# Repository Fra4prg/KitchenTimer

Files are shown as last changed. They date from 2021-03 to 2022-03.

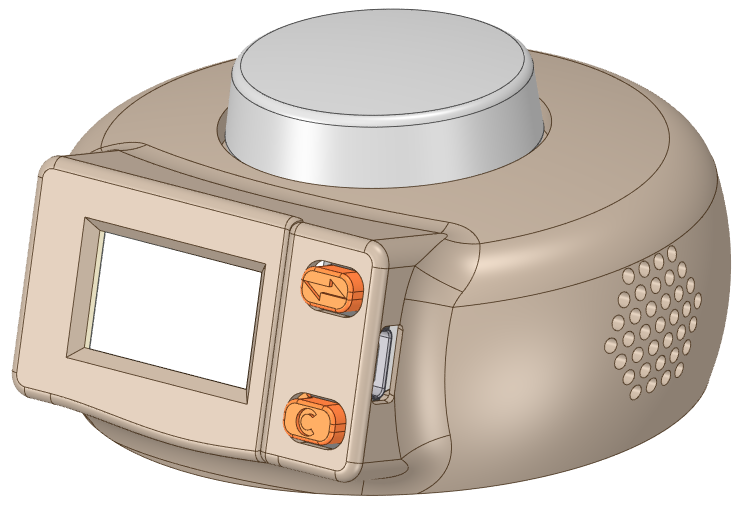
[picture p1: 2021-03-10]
pictures/Kitchen_Timer_1.png

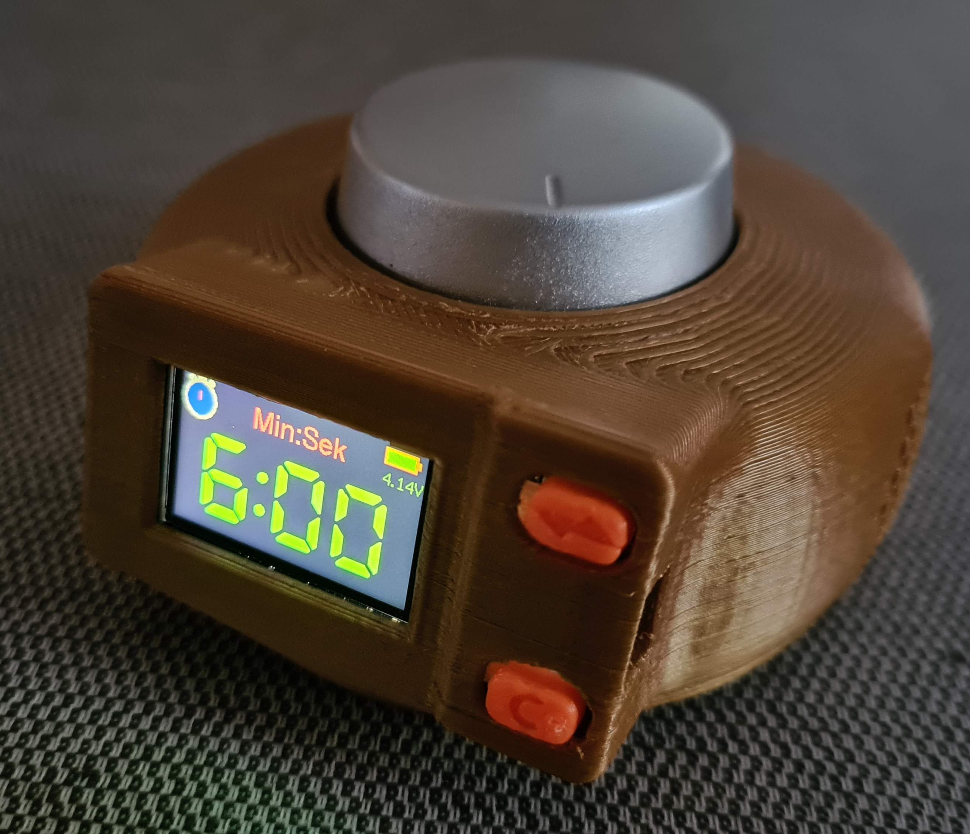
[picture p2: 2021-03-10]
pictures/Kitchen_Timer_4.JPG

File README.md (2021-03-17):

# KitchenTimer
Nice Kitchen Timer using LilyGO TTGO T-Display

You can set hours/minutes or minutes/seconds.
In the Configuration.h you can choose to use a rotary enconder (recommended) or 4 external Buttons, set colors, timing, language, ...

In the first version I had no separat power switch and just set the ESP32 to deepsleep.
The display draws 300µA in deepsleep which is pretty much for the battery but a simple solution. 
But the main problem is that the connected audion amplifier draws another 4-5mA. Hence the battery is empty after few days or less.
So at least the amplifier must be switched off, e.g. by a transistor.
I decided to install the full solution: a small additional circuit switches off the battery completely.
Charging via USB is still possible when timer is switched on.

Usage:

Switch on by pressing the rotary button.
After power on the timer is in stopped state.
Here you can set the time by rotaty encoder. Select setting left or right part of colon with the upper button of the TTGO display.
Select between Minutes/Seconds or Hours/Minutes with the lower button. The selection is shown in the header and the color of the time digits.
- Minutes/Seconds mode: 0 to 99 minutes can be selected, the time digits are green
- Hours/Minutes mode: 0 to 99 hours can be selected, the time digits are cyan

Start the timer by pressing the rotary button.
Time is counting down until 0:00 anf the progress bar gets smaller.
At the end it rings. 
If you don't press any button it rings again every minute until a button is pressed.
Pressing a button resets the time to start.

The timer can be paused by pressing the rotary button.
Pressing the button again continues.
The buttons of the display reset the timer.

There is no power off button.
Power is switches off automatically after 30 seconds of inactivity, except during countdown.

The following parts are needed:
- LilyGO TTGO T-Display
- rotary button (2-step or 4-step type is possible, see configuration.h)
- a small audio amplifier for 3-5V supply
- a small speaker
- a chargable Lithium battery 3.7V, e.g. 500-1000mAh
- a small DIY printed board an electrinic parts according the attached schematic

Case is provided for 3D printout.

Kitchen_Timer_4_small

The 3D print exploded:

Kitchen_Timer_1
Kitchen_Timer_2
Kitchen_Timer_3

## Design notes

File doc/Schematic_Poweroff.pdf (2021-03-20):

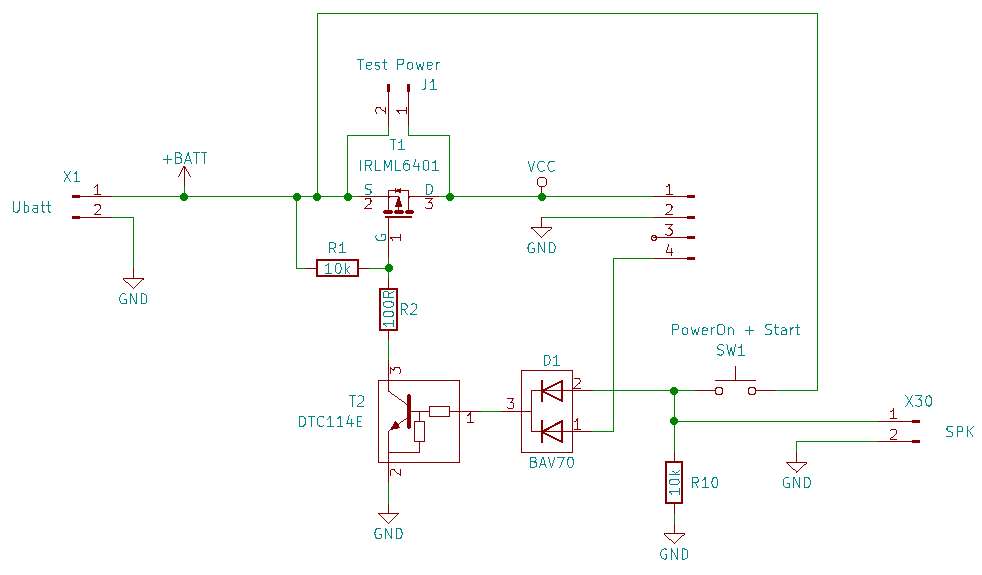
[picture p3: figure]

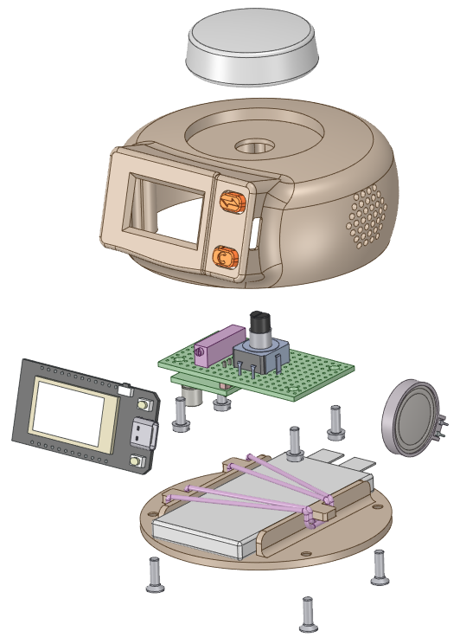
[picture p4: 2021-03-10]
pictures/Kitchen_Timer_2.png

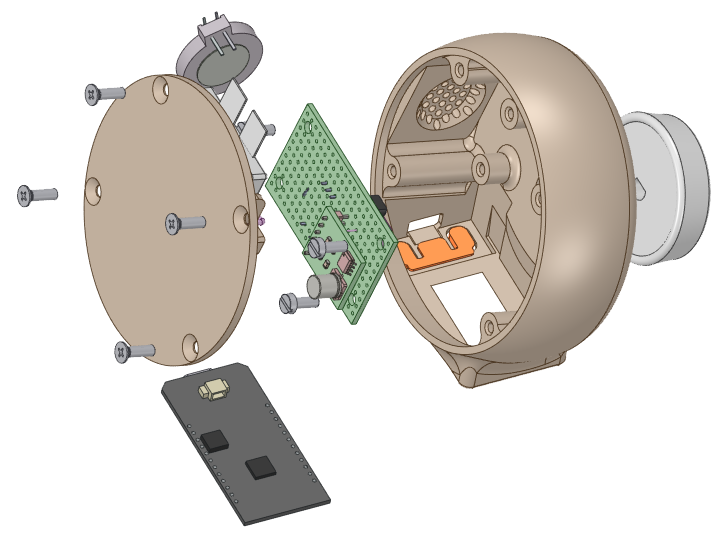
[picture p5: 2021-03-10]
pictures/Kitchen_Timer_3.png

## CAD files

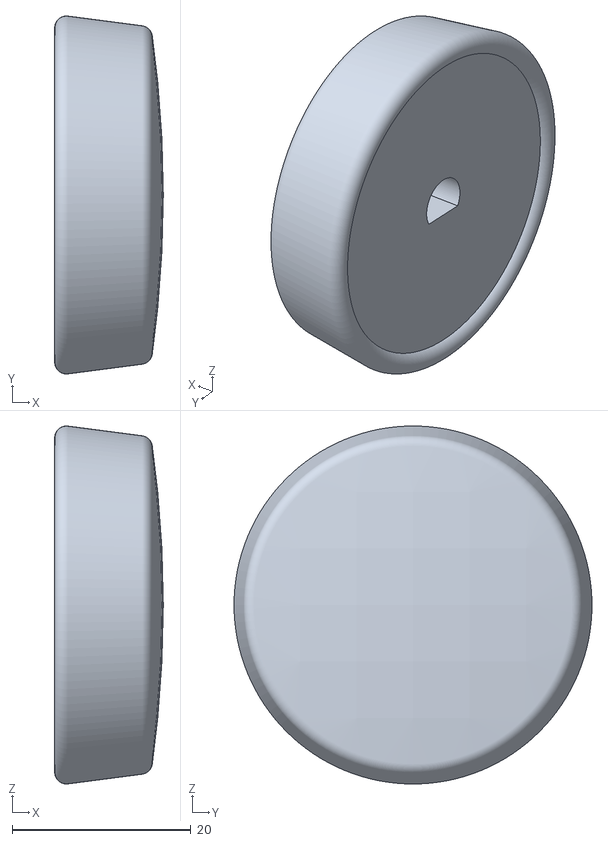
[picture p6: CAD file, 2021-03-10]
Case/Kitchen_Timer_Knob.stl
12.2 x 40.0 x 40.0

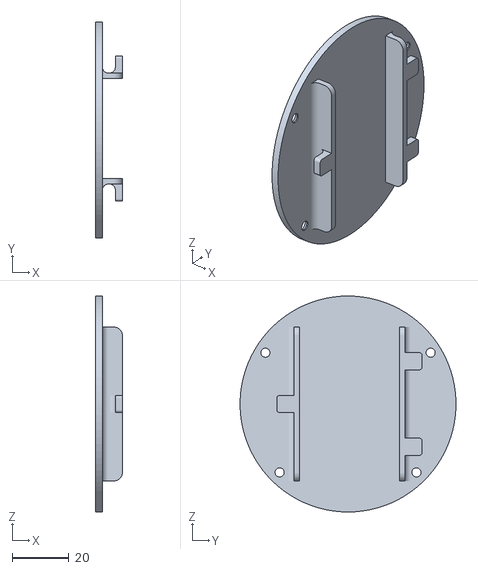
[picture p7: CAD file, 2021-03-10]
Case/Kitchen_Timer_Bottom.stl
9.44 x 75.8 x 75.8

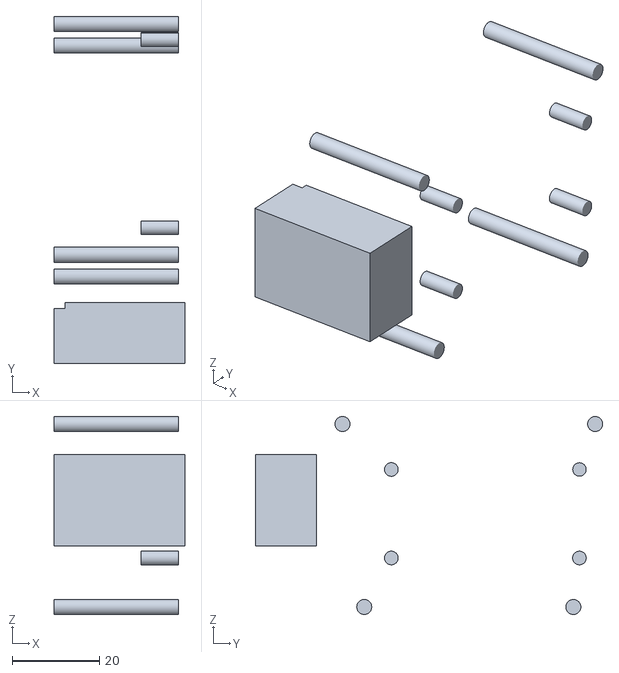
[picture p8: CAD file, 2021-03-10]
Case/Blocker.stl
30.0 x 79.7 x 45.5

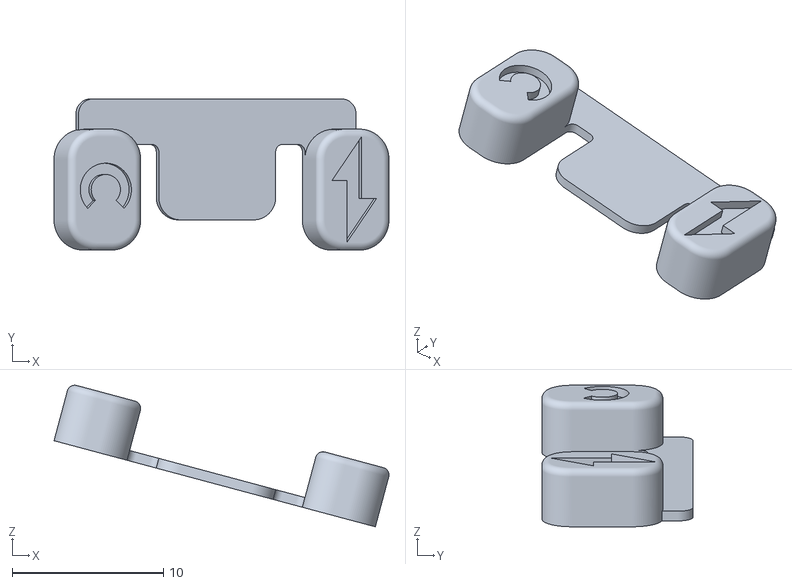
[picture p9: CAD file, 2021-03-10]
Case/Kitchen_Timer_Buttons.stl
22.2 x 10.00 x 9.36

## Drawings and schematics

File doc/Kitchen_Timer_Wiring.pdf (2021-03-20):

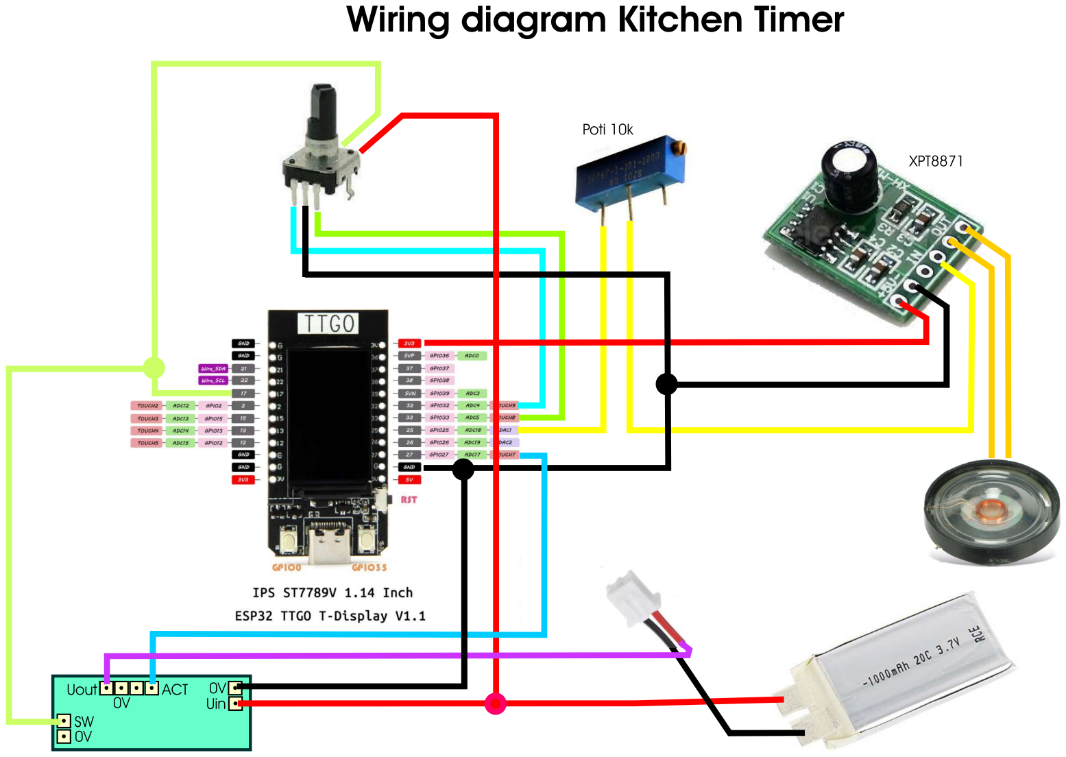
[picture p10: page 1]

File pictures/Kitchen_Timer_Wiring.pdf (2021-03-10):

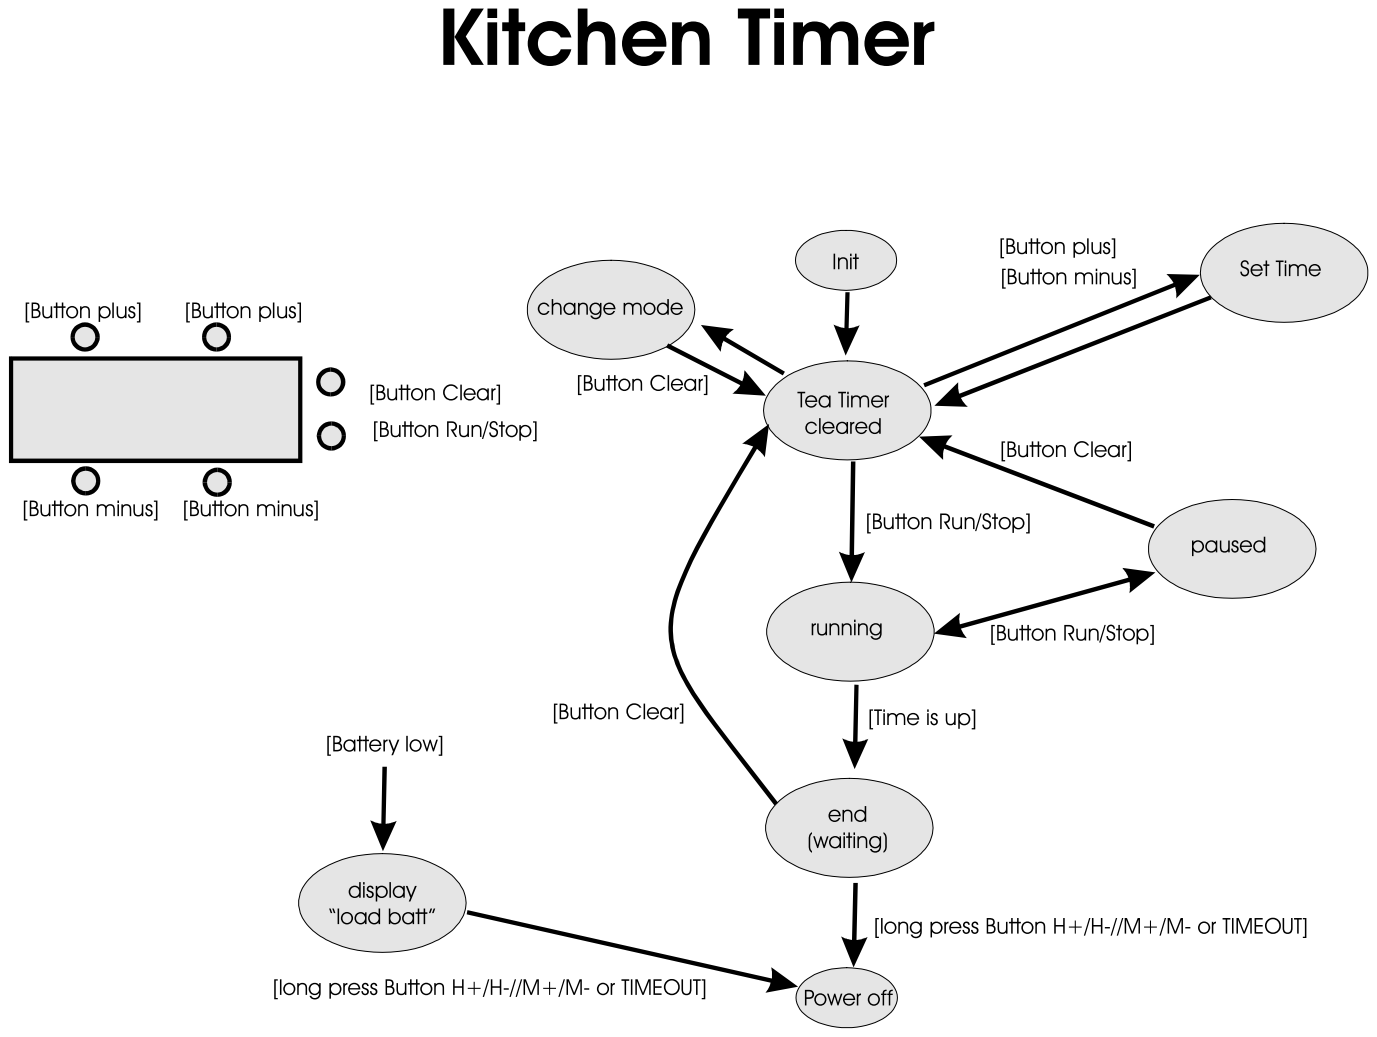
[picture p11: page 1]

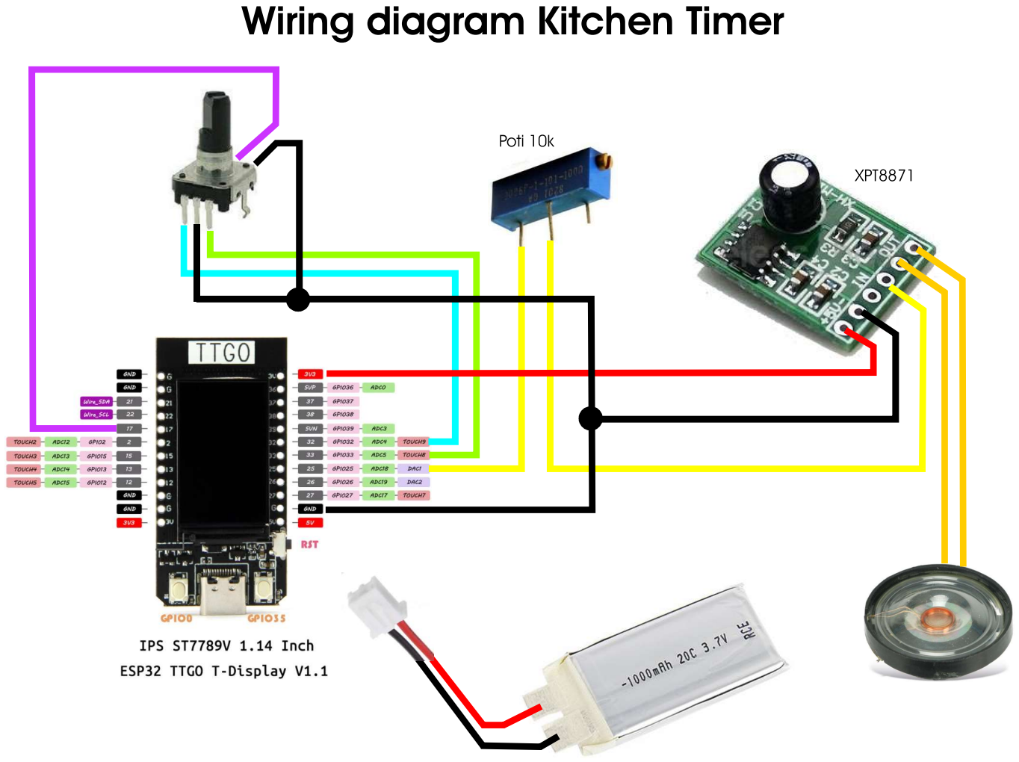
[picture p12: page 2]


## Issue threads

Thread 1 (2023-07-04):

EEPROM issue

zpowellman, 2023-07-04:
Hi,  I like your project. Thanks for submitting.  It works nicely and  looks good on the display.  Unfortunately, I have a problem with the EEPROM code.  When the app calls EEPROM.begin(), the system just hangs.  If I comment out the EEPROM initialization code,  it all works, albeit without EEPROM functions.  I've selected 'ESP32 Dev Module' and I'm using the 'ESP32 core 2.0.9.'  What version were you using?  I assume you selected the default 4Mbytes with spiffs configuration?  It's probably my T-Display device, but I thought I'd ask.

Fra4prg, 2023-07-08:
Hi Dan,
honestly I cannot answer your question.
When I develloped this Code everything was running. I did not change anything so far and the timer is running well.
Maybe you choosed the wrong board? Or you need to update one or more libraries or boards?
I remember I read an artcle where some boards had an issue that no EEPROM was populated on there was no connection to the EEPROM on the pcb. But I don't remember if this specific board was affected.
Can you try another code that uses the EEPROM just to prove that the board is working well? Maybe an example from the EEPROM library?

zpowellman, 2023-07-08:
The EEPROM example works just fine.  Is your T-Display a 4M or a 16M flash device?  I didn't see any description in your documentation.  Mine is 4M.  I've noticed other functions aren't working in my implementation...such as Hour/Minute selection.  The encoder and display function fine and the alarm works, but that's all.  I'm going to get a 16M version and give it a go.  Thanks for your response.  BTW. All my libraries are up to date.

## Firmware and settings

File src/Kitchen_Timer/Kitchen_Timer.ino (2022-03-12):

/*
  Kitchen_Timer2

  For this updated Version 
     - the option to switch to hours/minutes can be disabled in Configuration.h disabled
     - a warning sound appears before undervoltage shutdown
     - in Configuration.h you ca select whether Seconds are always set to 00 at startup or set to last value

  Display
  [disabled: hh:mm for times >1h00]
  mm:ss for times 1m00..59m59

  Configuration options see "Configuration.h"

  Make sure LOAD_GFXFF is defined in the used User_Setup file
  within the library folder.

  select the development board  **ESP32 Dev Module**

  #########################################################################
  ###### DON'T FORGET TO UPDATE THE User_Setup.h FILE IN THE LIBRARY ######
  ######   TO SELECT YOUR DISPLAY TYPE, PINS USED AND ENABLE FONTS   ######
  #########################################################################
*/

// ########################
// ToDo:
// - solve linker error: "dram0.data' will not fit in region `dram0_0_seg" so that warn sound can be used at LOW BATT shutdown
// - long button press for power off
// - Code optimization
// - check pixel set outside narrow string and refresh back if needed
// - charging: keep power on
// ########################

#include "SPI.h"
#include "TFT_eSPI.h"
#include "Adafruit_GFX.h"
#include "esp_adc_cal.h"
#include <EEPROM.h>
#include <WiFi.h>
#include <RotaryEncoder.h>
#include "Configuration.h"
#include "Kitchen_Timer.h"
#include "sunset_240x135.h"

#include "Alarm_Clock.h"
#include "harp.h"
#include "XT_DAC_Audio.h"

// linker error: dram0.data' will not fit in region `dram0_0_seg
//#include "warn.h"

// The custom font file attached to this sketch must be included
#include "DSEG7_Classic_Mini_Bold_72.h"
#define MYFONT &DSEG7_Classic_Mini_Bold_72

// clock pointer positions
uint8_t cp[9][4] {
    {CLOCK_POS_X, CLOCK_POS_Y, CLOCK_POS_X-5, CLOCK_POS_Y-5},  // [0] 10h30
    {CLOCK_POS_X, CLOCK_POS_Y, CLOCK_POS_X,   CLOCK_POS_Y-7},  // [1] 12h00
    {CLOCK_POS_X, CLOCK_POS_Y, CLOCK_POS_X+5, CLOCK_POS_Y-5},  // [2] 01h30
    {CLOCK_POS_X, CLOCK_POS_Y, CLOCK_POS_X+7, CLOCK_POS_Y},    // [3] 03h00
    {CLOCK_POS_X, CLOCK_POS_Y, CLOCK_POS_X+5, CLOCK_POS_Y+5},  // [4] 04h30
    {CLOCK_POS_X, CLOCK_POS_Y, CLOCK_POS_X,   CLOCK_POS_Y+7},  // [5] 06h00
    {CLOCK_POS_X, CLOCK_POS_Y, CLOCK_POS_X-5, CLOCK_POS_Y+5},  // [6] 07h30
    {CLOCK_POS_X, CLOCK_POS_Y, CLOCK_POS_X-7, CLOCK_POS_Y},    // [7] 09h00
    {CLOCK_POS_X, CLOCK_POS_Y, CLOCK_POS_X-5, CLOCK_POS_Y-5}   // [8] 10h30
};

#ifdef ROTARY_4STEP
// Setup a RotaryEncoder with 4 steps per latch for the 2 signal input pins:
RotaryEncoder encoder(ENCPIN1, ENCPIN2, RotaryEncoder::LatchMode::FOUR3);
#endif

#ifdef ROTARY_2STEP
// Setup a RotaryEncoder with 2 steps per latch for the 2 signal input pins:
RotaryEncoder encoder(ENCPIN1, ENCPIN2, RotaryEncoder::LatchMode::TWO03);
#endif

XT_Wav_Class Alarm(Alarm_Clock);      // create an object of type XT_Wav_Class that is used by 
                                      // the dac audio class (below), passing wav data as parameter.

XT_Wav_Class harpsound(harp);         // create an object of type XT_Wav_Class that is used by 
                                      // the dac audio class (below), passing wav data as parameter.

// linker error: dram0.data' will not fit in region `dram0_0_seg
//XT_Wav_Class warnsound(warn);         // create an object of type XT_Wav_Class that is used by 
                                      // the dac audio class (below), passing wav data as parameter.
                                      
XT_DAC_Audio_Class DacAudio(25,0);    // Create the main player class object. 
                                      // Use GPIO 25, one of the 2 DAC pins and timer 0

uint32_t DemoCounter=0;               // Just a counter to use in the serial monitor
                                      // not essential to playing the sound


// global variables
uint8_t   buttons;          // binary button pressed info, each bit represents a button
uint32_t  lasttime_button;  // for debouncing
char      buff[256];        // generic text buffer for printf
char      errortext[64];    // error text to display
uint32_t  set_time_hm;      // set time hours / minutes
uint32_t  set_time_ms;      // set time minutes / seconds
uint32_t  start_time;       // millis() at start of measuring
uint32_t  et;               // current remaining time to display
uint32_t  et_last;          // millis() at start of pause
uint32_t  eh_last, em_last, es_last;        // last h, m, s for detecting nedd of display update
uint8_t   eh, em, es;       // display numbers h, m, s of et
uint8_t   esh, esm, ess;    // display numbers h, m, s of set_time
uint8_t   clock_pointer;    // position of clock pointer 0..7
boolean   mode_HM;          // true=HH:MM, false=MM:SS
uint8_t   eNextState;       // FSM state
uint32_t  timeout_counter;  // timeout for auto power off [ms]
float     battery_voltage;  // measured battery voltage
uint32_t  updatetime, updatecolon;

// Use hardware SPI
TFT_eSPI tft = TFT_eSPI();

// ###############################################################################################

void drawClockPointer(void) {
  tft.drawLine(cp [clock_pointer]  [0], cp [clock_pointer]  [1], cp [clock_pointer]  [2], cp [clock_pointer]  [3], CLOCK_COL_FACE);    // erase old
  tft.drawLine(cp [clock_pointer+1][0], cp [clock_pointer+1][1], cp [clock_pointer+1][2], cp [clock_pointer+1][3], CLOCK_COL_POINTER); // draw new
}

void drawClockFace(void) {
  tft.fillCircle(CLOCK_POS_X,    CLOCK_POS_Y-18,  4, CLOCK_COL_KNOB);  // 3 dots
  tft.fillCircle(CLOCK_POS_X-10, CLOCK_POS_Y-16,  3, CLOCK_COL_KNOB);
  tft.fillCircle(CLOCK_POS_X+10, CLOCK_POS_Y-16,  3, CLOCK_COL_KNOB);

  tft.fillCircle(CLOCK_POS_X,    CLOCK_POS_Y,   17, CLOCK_COL_CASE);
  tft.fillCircle(CLOCK_POS_X,    CLOCK_POS_Y,   14, CLOCK_COL_FACE);

  clock_pointer = 0;
  drawClockPointer();
}

void show_battery() {
  // correction factor due to real measurement
  #define CORR 0.29
// read battery voltage
  uint16_t v = analogRead(ADC_PIN);
  battery_voltage = ((float)v / 4095.0) * 2.0 * 3.3 * (VREF / 1000.0) + CORR;
  String voltage = " " + String(battery_voltage) + "V";
  tft.setTextDatum(TR_DATUM);
  tft.setTextColor(BATCOL_VAL);
  tft.fillRect(BATVAL_POS_X-40, BATVAL_POS_Y, 40, 15, BATCOL_BACK);
  tft.drawString(voltage, BATVAL_POS_X, BATVAL_POS_Y, 2);

// battery symbol
  if(battery_voltage <= 2.99){
    tft.fillRect(BATSYM_POS_X,    BATSYM_POS_Y,    30,  14, BATCOL_FRAME_EMPTY); // body
    tft.fillRect(BATSYM_POS_X+30, BATSYM_POS_Y+4,   3,  6, BATCOL_FRAME_EMPTY); // right knob
    //tft.drawString(voltage, BATVAL_POS_X, BATVAL_POS_Y, 2);
  }
  else {
    tft.fillRect(BATSYM_POS_X,    BATSYM_POS_Y,    30,  14, BATCOL_FRAME); // body
    tft.fillRect(BATSYM_POS_X+30, BATSYM_POS_Y+4,   3,  6, BATCOL_FRAME); // right knob
  }
  tft.fillRect(BATSYM_POS_X+2, BATSYM_POS_Y+2, 26, 10, BATCOL_BACK); // clear level symbol


  if(battery_voltage >= 4.0){
    tft.fillRect(BATSYM_POS_X+2, BATSYM_POS_Y+2, 26, 10, BATCOL_FULL);
  }
  else if(battery_voltage >= 3.8){
    tft.fillRect(BATSYM_POS_X+2, BATSYM_POS_Y+2, 21, 10, BATCOL_FULL);
  }
  else if(battery_voltage >= 3.6){
    tft.fillRect(BATSYM_POS_X+2, BATSYM_POS_Y+2, 16, 10, BATCOL_MID);
  }
  else if(battery_voltage >= 3.4){
    tft.fillRect(BATSYM_POS_X+2, BATSYM_POS_Y+2, 11, 10, BATCOL_MID);
  }
  else if(battery_voltage >= 3.2){
    tft.fillRect(BATSYM_POS_X+2, BATSYM_POS_Y+2, 6, 10, BATCOL_LOW);
  }
  else if(battery_voltage >= 3.0){
    tft.fillRect(BATSYM_POS_X+2, BATSYM_POS_Y+2, 4, 10, BATCOL_LOW);
  }
  if(battery_voltage >= 4.60){
    tft.setTextColor(BATCOL_TXT);
    tft.drawString("CHG", BATSYM_POS_X+28, BATSYM_POS_Y-1, 2);
  }
  else if(battery_voltage >= 4.85){
    tft.setTextColor(BATCOL_TXT);
    tft.drawString("USB", BATSYM_POS_X+28, BATSYM_POS_Y-1, 2);
  }
}

void update_progressbar(uint8_t pmode, uint16_t pvalue,  uint16_t maxval) {
  uint16_t progbar_color_bar, progbar_color_frame;
  uint16_t  progbar;

  // select colors
  if (pmode & RUN) {
    progbar_color_bar = PROGBAR_COL_BAR;
    progbar_color_frame = PROGBAR_COL_FRAME;
  }
  if (pmode & END) {
    progbar_color_bar = PROGBAR_COL_BAR_OVL;
    progbar_color_frame = PROGBAR_COL_FRAME_OVL;
  }
  if (pmode & PAUSE) {
    progbar_color_bar = PROGBAR_COL_BAR_PAUSE;
    progbar_color_frame = PROGBAR_COL_FRAME_PAUSE;
  }

  // select style
  if (pmode & BACK) { // fill background
    tft.fillRect(0, PROGBAR_POS_Y-2, 240, PROGBAR_HEIGHT+4, TIME_COL_BACK); // background progress bar
  }
  if (pmode & FRAME) { // draw frame
    tft.drawRect(0, PROGBAR_POS_Y, 240, PROGBAR_HEIGHT, progbar_color_frame); // border progress bar
  }
  if (pmode & FULL) { // fill full bar
    tft.fillRect(2, PROGBAR_POS_Y+2, 236, PROGBAR_HEIGHT-4, progbar_color_bar); // filled progress bar
  }
  if (pmode & PART) { // decrease progress bar
    progbar = 236 * ((float)pvalue / (float)maxval);
    tft.fillRect((uint32_t)(progbar+2), PROGBAR_POS_Y+2, (uint32_t)(236-progbar), PROGBAR_HEIGHT-4, PROGBAR_COL_BACK);  
  }
  if (pmode & PARTP) { // increase progress bar
    progbar = 236 * ((float)pvalue / (float)maxval);
//    tft.fillRect((uint32_t)(progbar+2), PROGBAR_POS_Y+2, (uint32_t)(236-progbar), PROGBAR_HEIGHT-4, PROGBAR_COL_BACK);  
    tft.fillRect((uint32_t)2, PROGBAR_POS_Y+2, (uint32_t)progbar, PROGBAR_HEIGHT-4, progbar_color_bar);  
  }
}

void print_main_time(uint8_t h_m, uint8_t m_s, uint32_t color_f, uint32_t color_b) {
  
  tft.setTextDatum(TC_DATUM);
  tft.setTextColor(color_f, color_b);
      
  if (h_m<10) {
    // check pixel set outside narrow string and refresh back if needed
    tft.fillRect(0, TIME_POS_Y, 240, 73, color_b);
    sprintf(buff, "%01d:%02d", h_m, m_s);
  }
  else {
    sprintf(buff, "%02d:%02d", h_m, m_s);
  }
  tft.drawString(buff, 117, TIME_POS_Y, GFXFF);
}

void flash_main_time(uint8_t hm, uint8_t ms, uint32_t color_fl, uint32_t color_fr, uint32_t color_b) {
  uint8_t pos_l, pos_r;
  
  if (hm<10) {
    pos_l = 49;
    pos_r = 154;  
    sprintf(buff, "%01d", hm);
    // check pixel set outside narrow string and refresh back if needed
  }
  else {
    pos_l = 49;
    pos_r = 184;  
    sprintf(buff, "%02d", hm);
  }

  tft.setTextDatum(TC_DATUM);
//  if (color_fl == BLINKTIME_COL) {
  if ((color_fl == BLINKTIME_COL) || (color_fl == BLINKTIME_COL_HM)) {
    if (hm<10) {
      tft.fillRect(0, TIME_POS_Y, 40, 73, color_b);
    }
    tft.setTextColor(color_fl, color_b);
    tft.drawString(buff, pos_l, TIME_POS_Y, GFXFF);
  }
//  if (color_fr == BLINKTIME_COL) {
  if ((color_fr == BLINKTIME_COL) || (color_fr == BLINKTIME_COL_HM)) {
    if (hm<10) {
      tft.fillRect(200, TIME_POS_Y, 40, 73, color_b);
    }
    sprintf(buff, "%02d", ms);
    tft.setTextColor(color_fr, color_b);
    tft.drawString(buff, pos_r, TIME_POS_Y, GFXFF);
  }
}

// @brief The interrupt service routine will be called on any change of one of the input signals.
ICACHE_RAM_ATTR void checkPosition()
{
  encoder.tick(); // just call tick() to check the state.
}

#ifdef BUTTONS
void int_button_TL(void) {
  if ((millis() - lasttime_button) > DEBOUNCETIME) {
    buttons |= TL;
    lasttime_button = millis();
  }
}
void int_button_TR(void) {
  if ((millis() - lasttime_button) > DEBOUNCETIME) {
    buttons |= TR;
    lasttime_button = millis();
  }
}
void int_button_BL(void) {
  if ((millis() - lasttime_button) > DEBOUNCETIME) {
    buttons |= BL;
    lasttime_button = millis();
  }
}
void int_button_BR(void) {
  if ((millis() - lasttime_button) > DEBOUNCETIME) {
    buttons |= BR;
    lasttime_button = millis();
  }
}
#else
void int_button_CLR(void) {
  if ((millis() - lasttime_button) > DEBOUNCETIME) {
    buttons |= CLR;
    lasttime_button = millis();
  }
}
#endif

void int_button_MODE(void) {
  if ((millis() - lasttime_button) > DEBOUNCETIME) {
    buttons |= MD;
    lasttime_button = millis();
/*
    while (digitalRead(BUTTON_MODE) == LOW) {
      // wait for release
      delay(10);
    }
    if ((millis() - lasttime_button) > LONGPRESS) {
      buttons |= PO;
    }
*/
  }
}
void int_button_RUNSTOP(void) {
  if ((millis() - lasttime_button) > DEBOUNCETIME) {
    buttons |= RS;
    lasttime_button = millis();
  }
}
 
// ###############################################################################################
// ***** eventhandlers *****

uint8_t Stopped_Handler(void) {
#ifndef BUTTONS
  static int  pos = 0;         // position of rotary encoder
  int         newPos;
  boolean     setleft = true;
  uint8_t     setcount;
#endif

  // entry
#if DBGSW
  Serial.printf("entered Stopped_Handler\n");
#endif

  tft.fillScreen(CANVAS_COL);      // Clear screen
  tft.setTextDatum(TC_DATUM);

  drawClockFace();
  drawClockPointer();

  updatetime=millis();

#ifndef BUTTONS
  setcount = 0;
#endif

  buttons=ENC; // start with invalid button to enter the loop


  // main

  while (1) {
    while (buttons==0) {
      // wait for button      
      if ((millis() - updatetime) > 500) {
        show_battery();
        if(battery_voltage <= 2.99){
          return FSM_LOW_BATT; // emergency break
        }
        if (setcount>0) {
          if (setcount %2) {
            // flash maintime normal #################################################
            if (mode_HM) {
              print_main_time(eh, em, TIME_COL_HM, TIME_COL_BACK);
            }
            else {
              print_main_time(em, es, TIME_COL, TIME_COL_BACK);
            }
          }
          else {
            if (setleft) {
              // flash left part of maintime dimmed #################################################
              if (mode_HM) {
                flash_main_time(eh, em, BLINKTIME_COL_HM, TIME_COL_HM, TIME_COL_BACK);
              }
              else {
                flash_main_time(em, es, BLINKTIME_COL, TIME_COL, TIME_COL_BACK);
              }
            }
            else {
              // flash right part of maintime dimmed #################################################
              if (mode_HM) {
                flash_main_time(eh, em, TIME_COL_HM, BLINKTIME_COL_HM, TIME_COL_BACK);
              }
              else {
                flash_main_time(em, es, TIME_COL, BLINKTIME_COL, TIME_COL_BACK);
              }
            }
          }
          setcount--;
        }
        updatetime=millis();
      }
      if ((millis() - timeout_counter) > TIMEOUT) {
        return FSM_POWEROFF;
      }
      
      // Read the current position of the encoder and print out when changed.
      encoder.tick();
      newPos = encoder.getPosition();
      if (pos != newPos) {
        buttons |= ENC;
      }
    }

    timeout_counter = millis(); // reset timeout
#ifndef BUTTONS
  setcount = SETCOUNTNUMBER; // number of times to blink after rotaty action
#endif


#if DBGSW
      //Serial.printf("Stop->Button: %3d\n", buttons);
#endif
    // ***** Run *****
    if (buttons & RS) { // run
      buttons=0;
      start_time = millis();
      if (mode_HM) {
        et_last = set_time_hm;
      }
      else {
        et_last = set_time_ms;
      }
      return FSM_RUNNUNG;
    }

#if OPTION_HHMM
    // ***** Mode *****
    if (buttons & MD) { // change mode HH:MM <-> MM:SS
      //buttons=0;
      mode_HM = !mode_HM;
    }
#else

#endif

#ifdef BUTTONS
    // ***** hh/mm ++ *****
    if (buttons & TL) { // increase left digits
      //buttons=0;
      if (mode_HM) {
        if (set_time_hm <= (MAX_H * 3600000)) {
          set_time_hm += 3600000; // +hh
        }
      }
      else {
        set_time_ms += 60000; // +mm
      }
    }
    
    // ***** hh/mm -- *****
    if (buttons & BL) { // decrease left digits
      //buttons=0;
      if (mode_HM) {
        if (set_time_hm >= 3600000) {
          set_time_hm -= 3600000; // -hh
        }
      }
      else {
        if (set_time_ms >= 60000) {
          set_time_ms -= 60000; // -mm
        }
      }
    }
    
    // ***** mm/ss ++ *****
    if (buttons & TR) { // increase left digits
      //buttons=0;
      if (mode_HM) {
        set_time_hm += 60000; // +mm
      }
      else {
        set_time_ms += 1000; // +ss
      }
    }
    
    // ***** mm/ss -- *****
    if (buttons & BR) { // decrease left digits
      //buttons=0;
      if (mode_HM) {
        if (set_time_hm >= 60000) {
          set_time_hm -= 60000; // -mm
        }
      }
      else {
        if (set_time_ms >= 1000) {
          set_time_ms -= 1000; // -ss
        }
      }
    }
#else
    if (mode_HM) {
      if (((int)encoder.getDirection())>0) {
        if (setleft) {
          if (set_time_hm < ((MAX_H) * 60*60000)) {
            set_time_hm += (newPos-pos) * 60*60000; // +hh
          }
        }
        else {
          if (set_time_hm < ((MAX_H) * 60*60000)) {
            set_time_hm += (newPos-pos) * 60000; // +mm
          }
        }
      }
      else {  // minus
        if (setleft) {
          if (set_time_hm >= 60*60000) {
            set_time_hm += (newPos-pos) * 60*60000; // -hh
          }
        }
        else {
          if (set_time_hm >= 1000) {
            set_time_hm += (newPos-pos) * 60000; // -mm
          }
        }
      }
    }
    else {
      if (((int)encoder.getDirection())>0) {  // plus
        if (setleft) {
          if (set_time_ms < ((MAX_M) * 60*1000)) {
            set_time_ms += (newPos-pos) * 60*1000; // +mm
          }
        }
        else {
          if (set_time_ms < ((MAX_M) * 60*1000)) {
            set_time_ms += (newPos-pos) * 1000; // +ss
          }
        }
      }
      else {  // minus
        if (setleft) {
          if (set_time_ms >= 60*1000) {
            set_time_ms += (newPos-pos) * 60*1000; // -mm
          }
        }
        else {
          if (set_time_ms >= 1000) {
            set_time_ms += (newPos-pos) * 1000; // -ss
          }
        }
      }
    }
    pos = newPos;

    if (buttons & (CLR)) { // change set left / right
      setleft = !setleft;
      setcount = SETCOUNTNUMBER; // number of times to blink after rotaty action
      // flash maintime normal #################################################
    }

#endif

    if (buttons & (PO)) { // power off
      buttons=0;
      return FSM_POWEROFF;
    }
    
    if (buttons) { // any set button pressed?
      if (mode_HM) {
#if EE_MODE_HM == 2
        EEPROM.write(EE_MODE, 1);
#endif
        EEPROM.write(EE_HM_H, ((set_time_hm - (set_time_hm % 3600000)) / 3600000));
        EEPROM.write(EE_HM_M, (((set_time_hm % 3600000) - (set_time_hm % 60000)) / 60000));
      }
      else {
#if EE_MODE_HM == 2
        EEPROM.write(EE_MODE, 0);
#endif
        EEPROM.write(EE_MS_M, ((set_time_ms - (set_time_ms % 60000)) / 60000));
        EEPROM.write(EE_MS_S, (((set_time_ms % 60000) - (set_time_ms % 1000)) / 1000));
      }
      delay(20);
#if DBGSW
      EEPROM.commit();
      Serial.printf("write EEPROM as:\n");
      Serial.printf("EE_INIT=%d, EE_MODE=%d, EE_HM_H=%d, EE_HM_M=%d, EE_MS_M=%d, EE_MS_S=%d\n", 
      EEPROM.read(EE_INIT), EEPROM.read(EE_MODE), EEPROM.read(EE_HM_H), EEPROM.read(EE_HM_M), EEPROM.read(EE_MS_M), EEPROM.read(EE_MS_S));
#endif
    }
    buttons=0;

    // update display
    tft.setTextDatum(TC_DATUM);
    tft.setTextColor(STARTTIME_COL, STARTTIME_COL_BACK);
    tft.fillRect(70, 10, 100, 22, STARTTIME_COL_BACK);
    if (mode_HM) {
      tft.drawString(STR_HM, 120, 10, 4);
      et = set_time_hm;
    }
    else {
      tft.drawString(STR_MS, 120, 10, 4);
      et = set_time_ms;
    }

    es = (et / 1000) % 60;
    if (mode_HM) {
      em = (et / 60000) % 60;
    }
    else {
      em = (et / 60000) % 100; // display up to 99 minutes
    }
    eh = (et / 3600000);
    
    // print main time
    if (mode_HM) {
      print_main_time(eh, em, TIME_COL_HM, TIME_COL_BACK);
    }
    else {
      print_main_time(em, es, TIME_COL, TIME_COL_BACK);
    }
    buttons=0; // clear invalid buttons
  }
}
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
void loop() {
// the state machine
#if DBGSW
  Serial.printf("State change eNextState = %d\n", eNextState);
//      Serial.printf("set_time:%d | et_last:%d | start_time:%d | et:%d |\n", set_time, et_last, start_time, et);
#endif

  switch(eNextState) {
    case FSM_STOPPED:
      eNextState = Stopped_Handler();
      break;
    case FSM_RUNNUNG:
      eNextState = Running_Handler();
      break;
    case FSM_PAUSED:
      eNextState = Paused_Handler();
      break;
    case FSM_END:
      eNextState = End_Handler();
      break;
    case FSM_POWEROFF:
      eNextState = Poweroff_Handler();
      break;
    case FSM_LOW_BATT:
      eNextState = Lowbatt_Handler();
      break;
    case FSM_ERROR:
      eNextState = Error_Handler(errortext);
      break;
    default:
      eNextState = Error_Handler("Wrong FSM State");
      break;
  }
}

// ###############################################################################################

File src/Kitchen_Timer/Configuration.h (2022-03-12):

/*
  Kitchen_Timer Configuration

  Display Settings

  You can select between 6 Button Interface

  +---------------------------------------------+
  |  [set + h/m]   [set + m/s]                  |
  |                               [Mode/Clear]  |
  |     8    8   :   8    8                     |
  |                                [Run/Stop]   |
  |  [set - h/m]   [set - m/s]                  |
  +---------------------------------------------+

  or Rotary Encoder plus 3 Buttons Interface

                    [Run/Stop]
         (    <--  Rotary Encoder  -->   )
  +---------------------------------------------+
  |                                             |
  |                                 [Mode]      |
  |     8    8   :   8    8                     |
  |                                 [Clear]     |
  |                                             |
  +---------------------------------------------+


*/
#ifndef KITCHENTIMER_CONFIGURATION_H
#define KITCHENTIMER_CONFIGURATION_H

// ***** Symbol / Graphics *****

// Canvas
#define CANVAS_COL              TFT_BLACK

// Battery Symbol
#define BATSYM_POS_X            202
#define BATSYM_POS_Y            4
#define BATCOL_FRAME            TFT_BROWN
#define BATCOL_FRAME_EMPTY      TFT_RED
#define BATCOL_BACK             TFT_BLACK
#define BATCOL_FULL             TFT_DARKGREEN
#define BATCOL_MID              TFT_ORANGE
#define BATCOL_LOW              TFT_RED
#define BATCOL_TXT              TFT_BLACK
#define BATVAL_POS_X            240
#define BATVAL_POS_Y            22
#define BATCOL_VAL              TFT_DARKGREEN

// Progress Bar
#define PROGBAR_POS_Y           123
#define PROGBAR_HEIGHT          12
#define PROGBAR_COL_FRAME       TFT_DARKGREEN
#define PROGBAR_COL_BAR         TFT_DARKGREEN
#define PROGBAR_COL_FRAME_OVL   TFT_RED
#define PROGBAR_COL_BAR_OVL     TFT_RED
#define PROGBAR_COL_FRAME_PAUSE TFT_DARKGREY
#define PROGBAR_COL_BAR_PAUSE   TFT_DARKGREY
#define PROGBAR_COL_BACK        TFT_BLACK

// Main Time
#define TIME_POS_Y              47
#define TIME_COL                TFT_GREEN
#define TIME_COL_HM             TFT_CYAN
#define TIME_COL_BACK           TFT_BLACK
#define STARTTIME_COL           TFT_RED
#define STARTTIME_COL_BACK      TFT_BLACK
#define PAUSETIME_COL           TFT_DARKGREY
#define PAUSETIME_COL_BACK      TFT_BLACK
#define BLINKTIME_COL           TFT_DARKGREEN
#define BLINKTIME_COL_HM        TFT_DARKCYAN

// Charge
#define CHARGE_COL_BACK         TFT_BLACK
#define CHARGE_COL_TEXT         TFT_RED


// Clock Icon (Position = Center of the clock)
#define CLOCK_POS_X             19
#define CLOCK_POS_Y             21
#define CLOCK_COL_CASE          TFT_DARKGREY
#define CLOCK_COL_KNOB          TFT_DARKGREY
#define CLOCK_COL_FACE          TFT_NAVY
#define CLOCK_COL_POINTER       TFT_RED

#define CLOCKSPEED              150           // Milliseconds Interval clock pointer
#define COLONSPEED              1000          // Milliseconds Interval Colon ar run

#define STARTSCREENDELAY        2000          // Time to show the startup screen
#define TIMEOUT                 30*1000       // timeout for auto power off [ms]
#define TIMEOUT_END             10*60*1000    // timeout for auto power off during END state (waiting for button) [ms]
#define SOUND_TIMEOUT           60*1000       // timeout for repeating sound in end state [ms]
#define MAX_H                   24            // max set hours
#define MAX_M                   99            // max set minutes

#define EE_MODE_HM              1             // 0=always start in Mode HH:MM, 1=always start in Mode MM:SS, 2=remember last mode from EEPROM
#define OPTION_HHMM             FALSE         // TRUE: Button can switch between MM:SS and HH:MM, FALSE: only MM:SS available
#define MMSS_SEC_RESTORE        FALSE         // TRUE: restor seconds from EEPROM at power on, FALSE: seconds always 00 at power on


// ***** Language *****
// select only one !
//#define LANG_EN     // english (default)
#define LANG_DE     // german
//#define LANG_HU     // hungarian
//#define LANG_IT     // italian
//#define LANG_ES     // spanish

// ***** Hardware *****
#define ADC_EN                  14
#define ADC_PIN                 34

// uncommend one of the following lines to select between rotary encoder or simple buttons
//#define BUTTONS
//#define ROTARY_2STEP
#define ROTARY_4STEP

// port pins for buttons
#ifdef BUTTONS
#define BUTTON_TL               33 // Button top left
#define BUTTON_TR               32 // Button top right
#define BUTTON_BL               17 // Button bottom left
#define BUTTON_BR               12 // Button bottom right
#define BUTTON_MODE              0 // Button onboard GPIO35
#define BUTTON_RUNSTOP          35 // Button onboard GPIO0
#define HOLD                    27 // keep power on
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

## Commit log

2021-03-10 Initial Version
    [Blocker.stl, Configuration.h, Kitchen_Timer_Bottom.stl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]
2021-03-20 Updates including power off circuit
    [Configuration.h]
2021-03-27 charging display added, minor bugfixes
    [Configuration.h]
2022-03-12 For this updated Version - the option to switch to hours/minutes can be disabled in Configuration.h disabled - in Configuration.h you ca select whether Seconds are always set to 00 at startup or set 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
    [Configuration.h]
